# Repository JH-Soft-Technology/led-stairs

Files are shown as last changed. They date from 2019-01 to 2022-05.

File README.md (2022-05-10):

# Ledstairs

Microcontroller operating stairway lighting via motion sensors and light intensity sensor. Has two [PIR motion sensors](https://en.wikipedia.org/wiki/Passive_infrared_sensor) to detect human or animal movement.
The board also has a light sensitivity sensor that prevents from triggering when there is still enough light.

It has been designed to be modularly applied to stairs of different sizes. Individual boards can be joined together and thus the possibility of lighting up the stairs with the number 8/16/24/32 steps.

If for some reason there are fewer steps than 8 or 16 or 24 or 32. It is possible to light up such a number of steps. The required number of slabs is connected and only the number of required steps is involved. In addition, the slots will be empty.

## Schematic

Board has one 12V input terminal. It's different to old version, because the old one has input for 12V and 5V independently. New design has only 12V input and it is redist for inner circuit to 5V voltage.

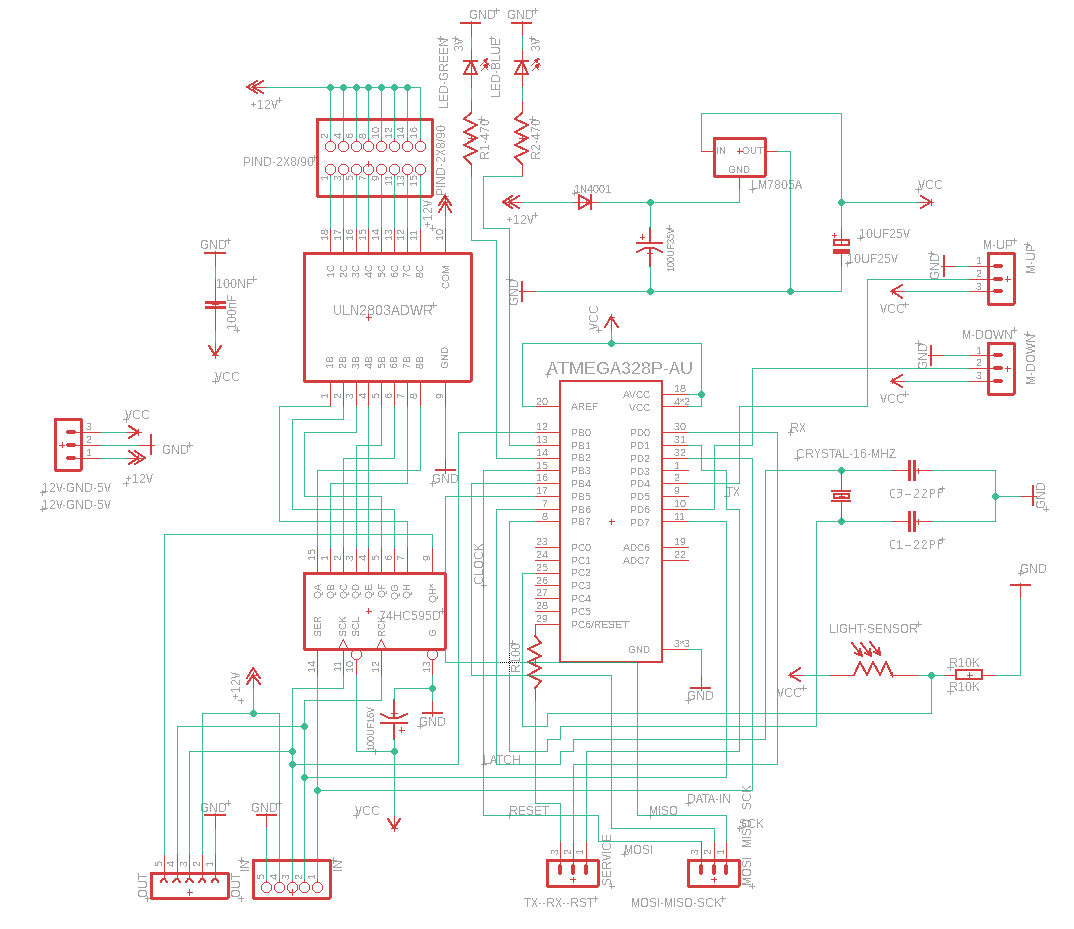
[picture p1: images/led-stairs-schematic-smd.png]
Schematic


## Design of the board

Board can be chained with up to 3 others. So maximal light management is 32 steps.

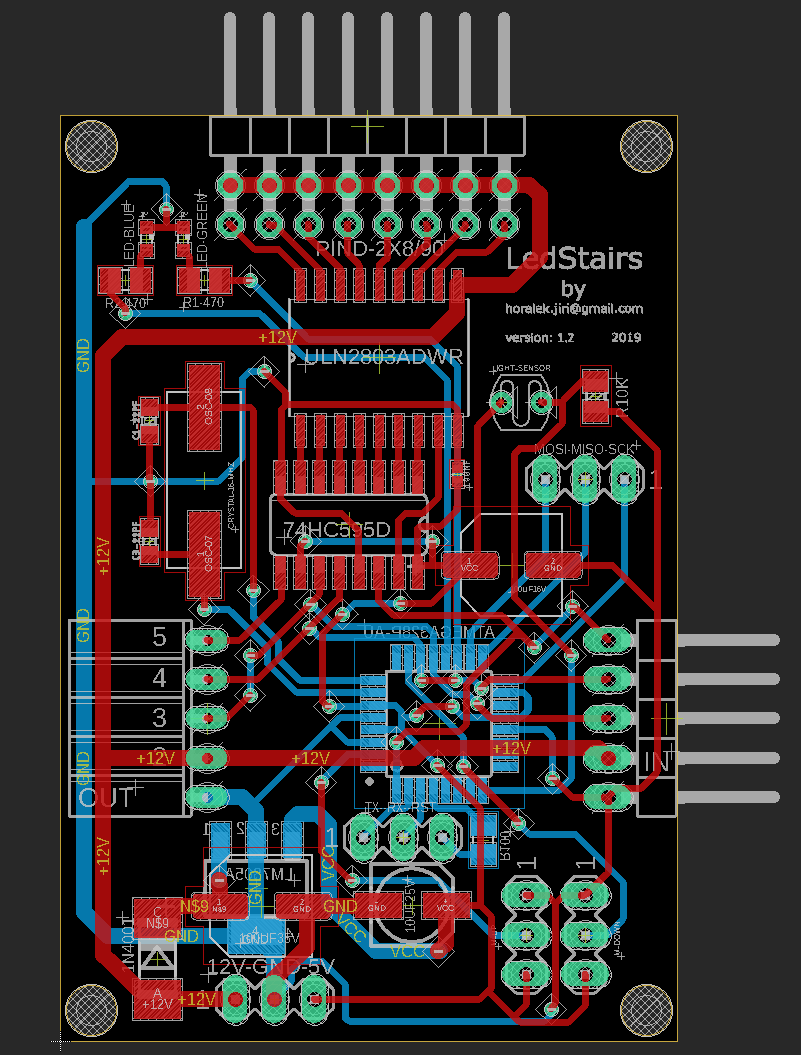
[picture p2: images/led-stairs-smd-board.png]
PCBdesign


## PCB board

It is double sided PCB board.

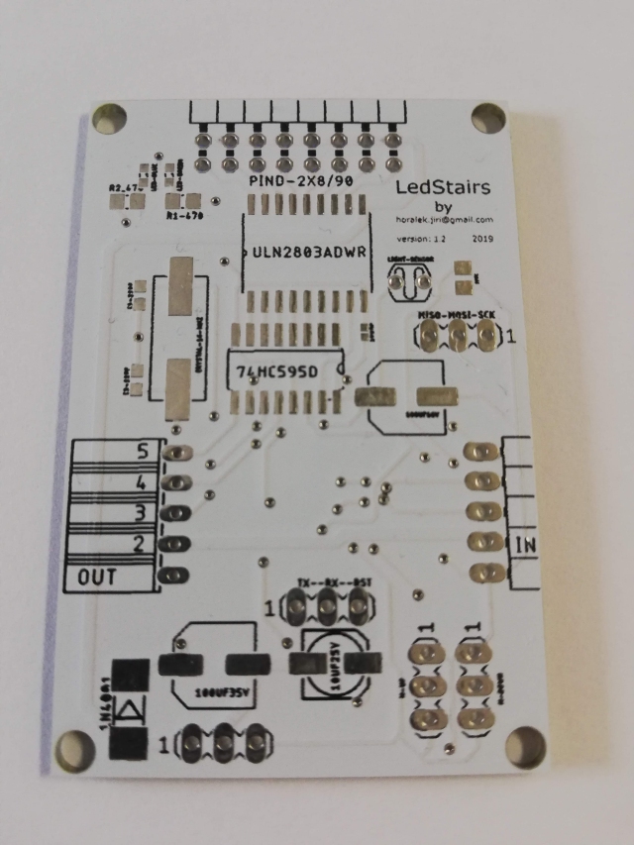
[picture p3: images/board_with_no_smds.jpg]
PCB


Master front side of the board with chips.

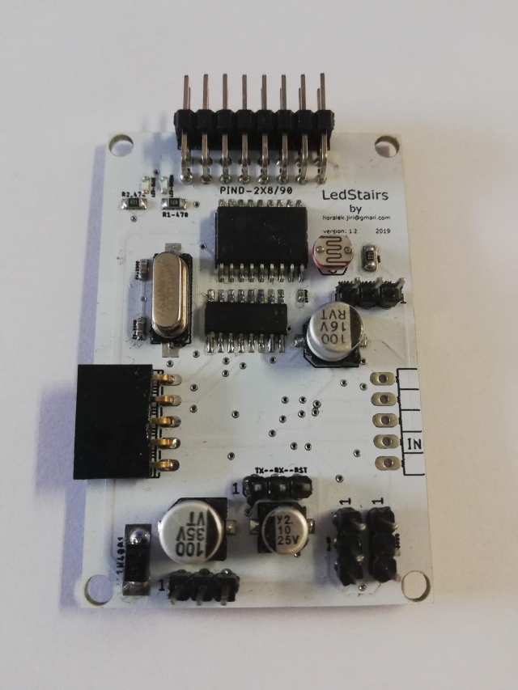
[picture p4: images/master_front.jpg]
PCBmasterFront


Master back side of the board with chips.

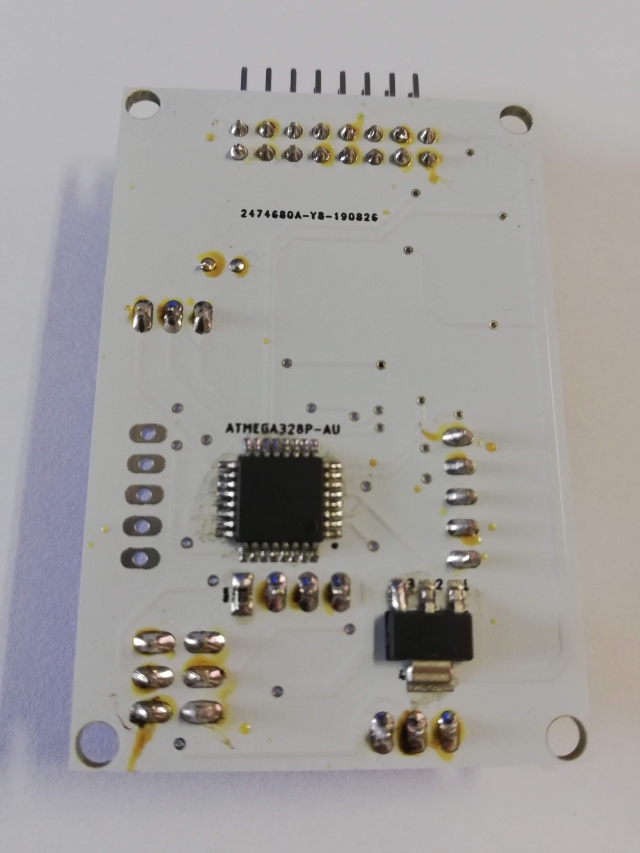
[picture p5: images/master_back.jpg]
PCBmasterBack


Master nad slave boards chained together.

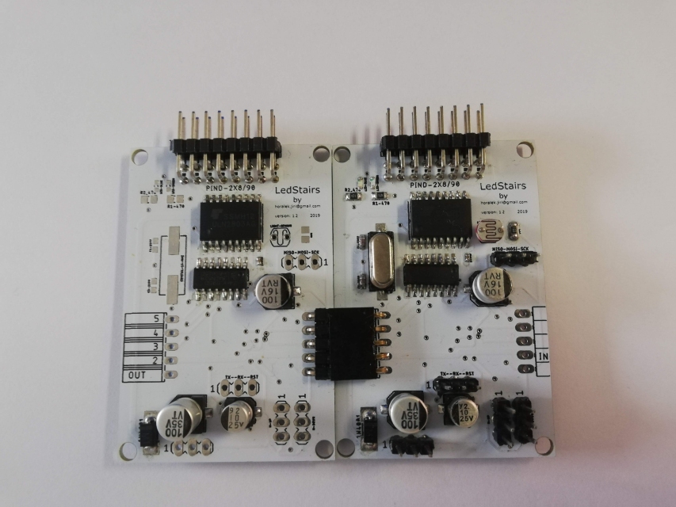
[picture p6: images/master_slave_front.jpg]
PCBmasterSlave


## How does it work

This board is turning on each step by step depends from which side is someone goes. Each step is turn on with little delay so it has nice effect. You can put a 12V LED strips to each step or
small light into the wall next to the each step. It depends on witch stairs you have.

In the feature, I'll put some video or moving picture in GIF format, how does it work.

## What you need to accomplish the project

- 12V power supply with current depends on number of the steps and length of LED strip. You need to calculate total current drain of all LED strips plus 25% extra for safe power supply operation.

Example:

```
You have 16 steps and each step has 70 cm long LED strip.
1m of led strip need 4,2 watts.

16 x 0,7 = 11,2m LED strip.

11,2 x 4,2 = 47,02 watts to all LED strips.

You need add 25% from 47,02 which is 58,75 watts.

So you need to by powers supply with 12V voltage and at least 60 watts. 60 watts for 12V power supply is 5 amps.
```

- 2 PIR sensor like [HC-SR501](https://www.amazon.com/HC-SR501/s?k=HC-SR501)
- A cable with two wires init. A cable cross section of at least 0,25 mm to each.
- Some 12V LED strips or lights at 12V.
- Some case for microcontroller and power supply.

## Visual

Up
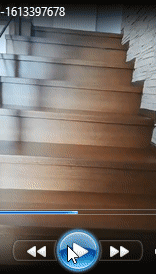
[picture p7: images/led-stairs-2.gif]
Down


## Authors

- **Jiří Horálek** - _Initial work_ - [jhoralek](https://github.com/jhoralek)

## License

This project is licensed under the MIT License - see the [LICENSE](LICENSE) file for details

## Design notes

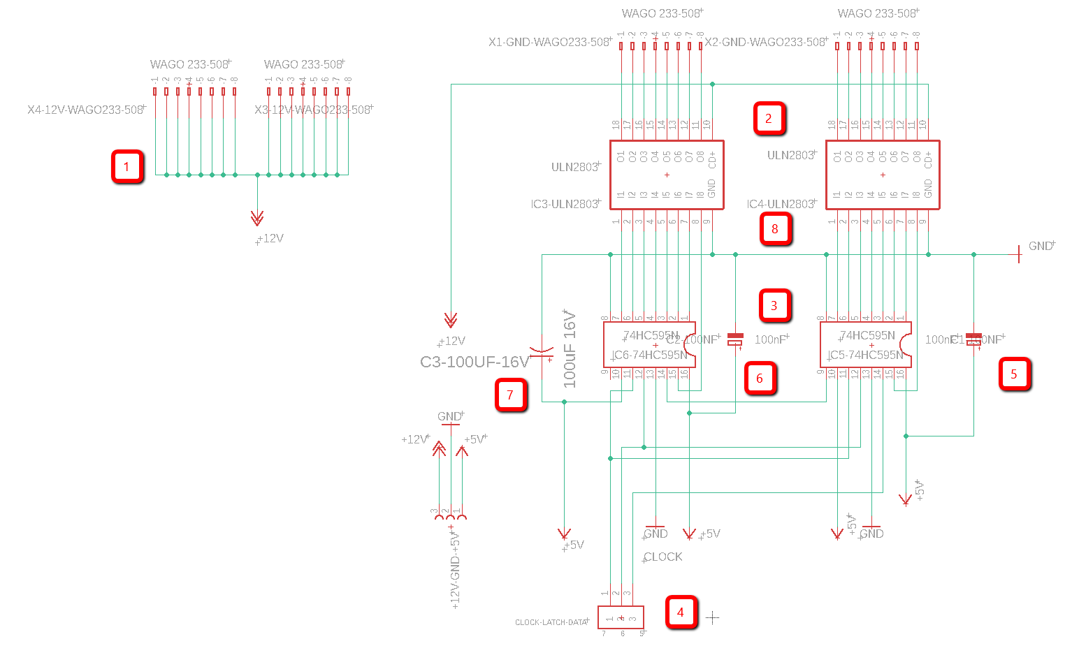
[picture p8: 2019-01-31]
images/schematic.png

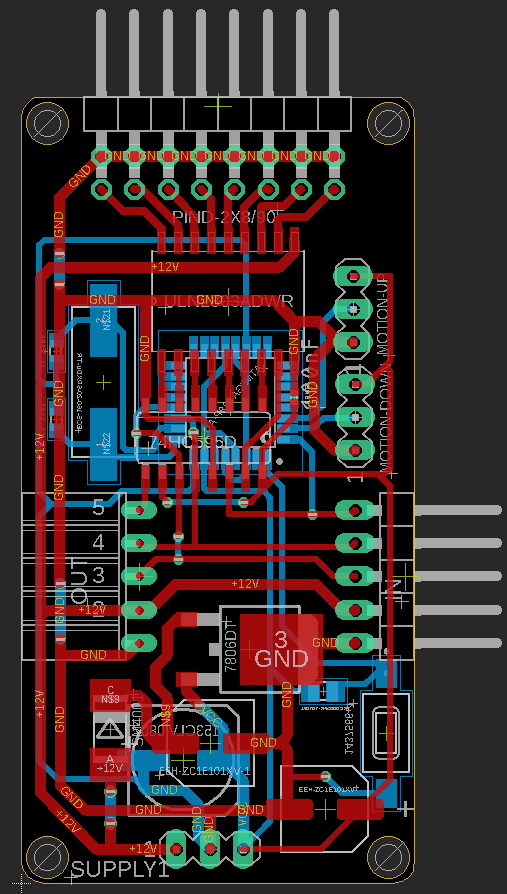
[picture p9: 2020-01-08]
images/board_upgrade.png

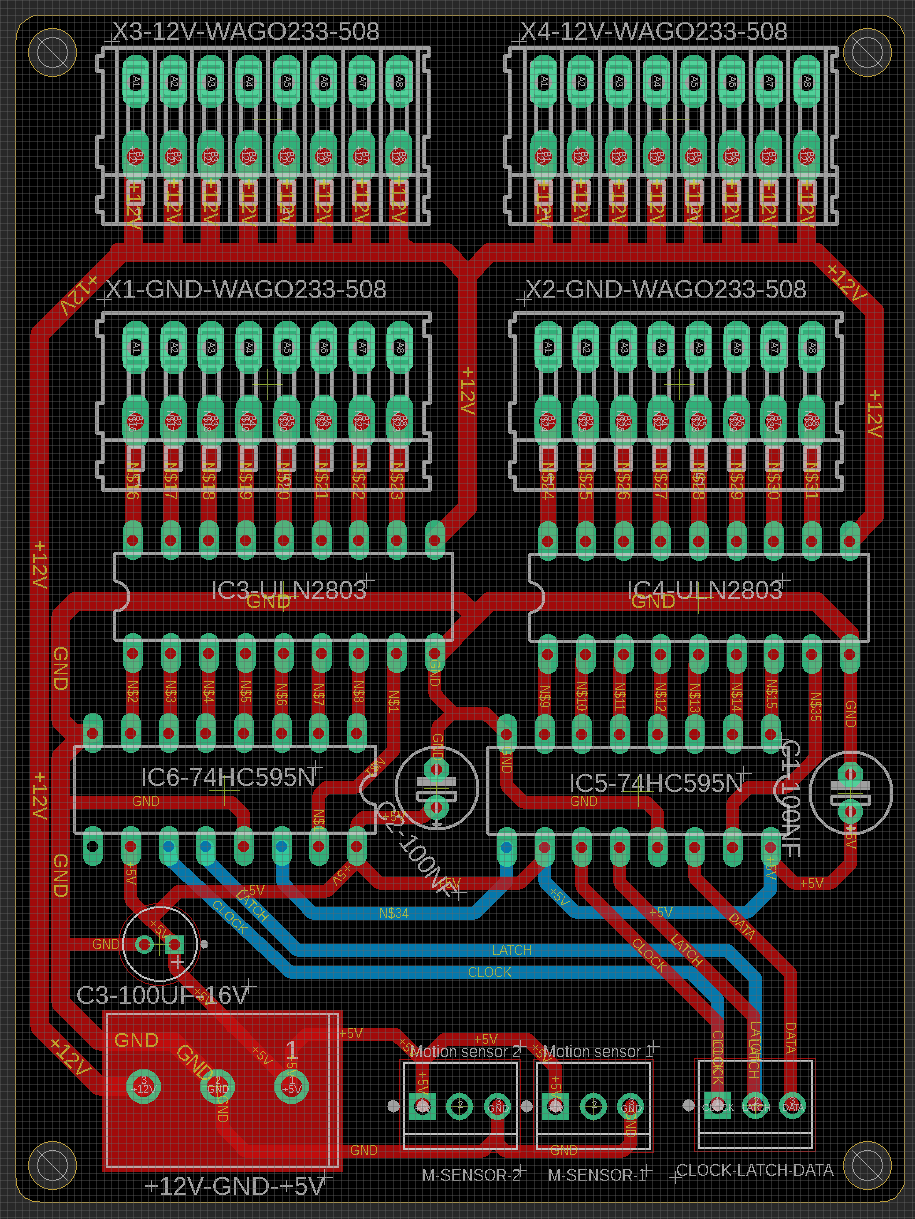
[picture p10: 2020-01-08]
images/board.png

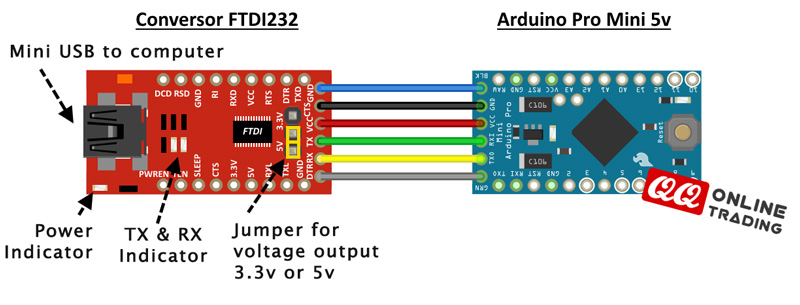
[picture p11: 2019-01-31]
images/arduino_wired_to_ftdi.jpg

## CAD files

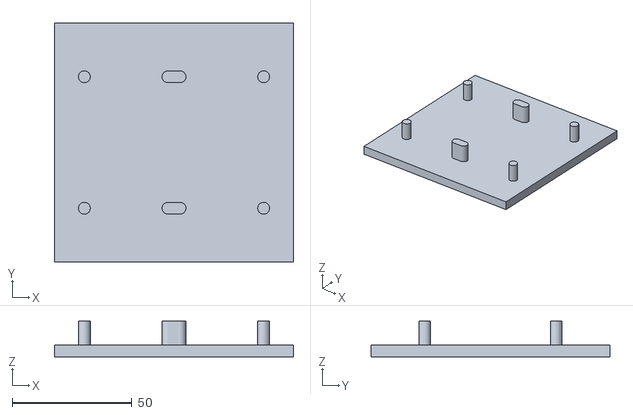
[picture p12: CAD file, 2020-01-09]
base_into_ko125e_wall_box.stl
100.0 x 100.0 x 15.0

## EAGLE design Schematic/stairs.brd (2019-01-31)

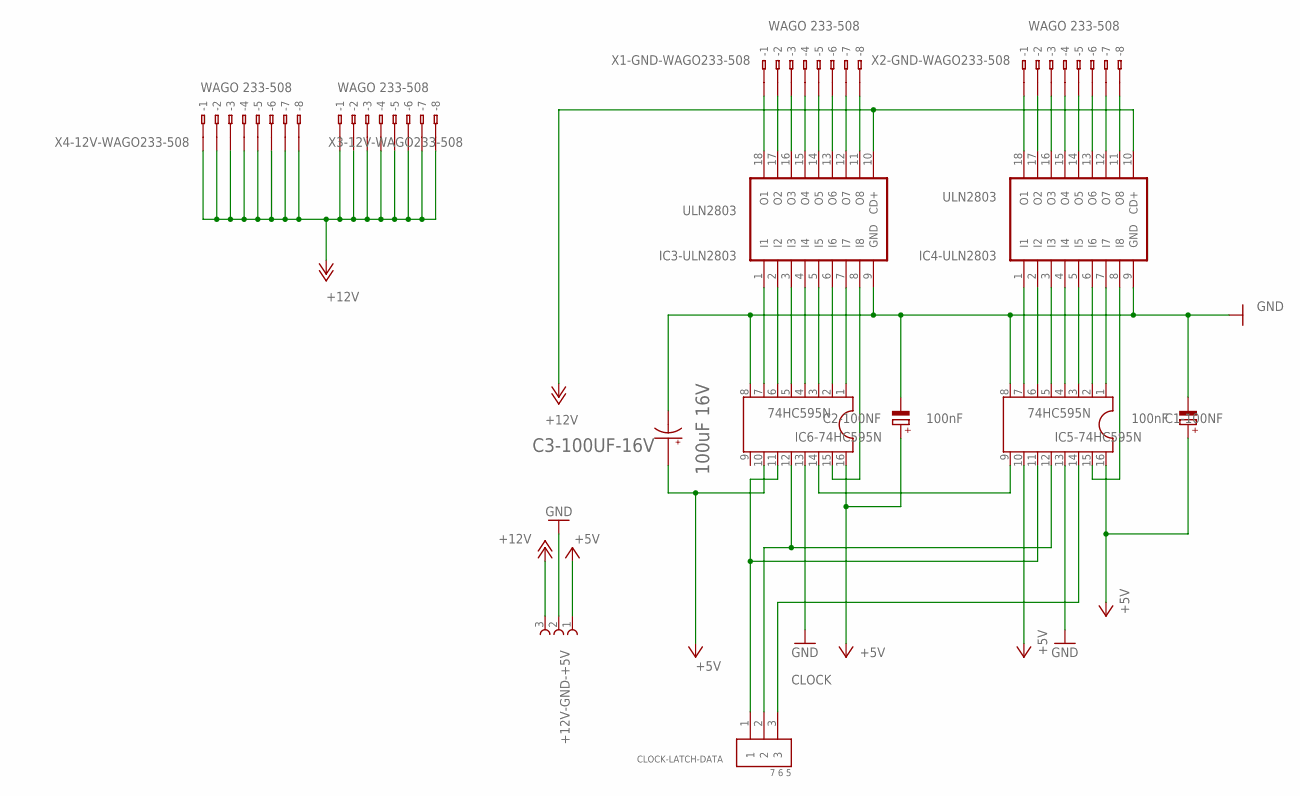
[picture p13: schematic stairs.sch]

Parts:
+12V-GND-+5V: +12V GND +5V; 691212710003
C1-100NF, C2-100NF: 100nF; E2,5-6E
C3-100UF-16V: 100uF 16V; CAPPRD200W50D500H1000
CLOCK-LATCH-DATA: 7 6 5; MOLEX_0022272031
IC3-ULN2803, IC4-ULN2803: ULN2803; DIL18
IC5-74HC595N, IC6-74HC595N: 74HC595N; DIL16
X1-GND-WAGO233-508, X2-GND-WAGO233-508, X3-12V-WAGO233-508, X4-12V-WAGO233-508: WAGO 233-508; 233-508

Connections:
+5V: +12V-GND-+5V.1, C1-100NF.+, C2-100NF.+, C3-100UF-16V.1, IC5-74HC595N.10, IC5-74HC595N.16, IC6-74HC595N.10, IC6-74HC595N.16
+12V: +12V-GND-+5V.3, IC3-ULN2803.10 (CD+), IC4-ULN2803.10 (CD+), X3-12V-WAGO233-508.B1 (B-1), X3-12V-WAGO233-508.B2 (B-2), X3-12V-WAGO233-508.B3 (B-3), X3-12V-WAGO233-508.B4 (B-4), X3-12V-WAGO233-508.B5 (B-5), X3-12V-WAGO233-508.B6 (B-6), X3-12V-WAGO233-508.B7 (B-7), X3-12V-WAGO233-508.B8 (B-8), X4-12V-WAGO233-508.B1 (B-1), X4-12V-WAGO233-508.B2 (B-2), X4-12V-WAGO233-508.B3 (B-3), X4-12V-WAGO233-508.B4 (B-4), X4-12V-WAGO233-508.B5 (B-5), X4-12V-WAGO233-508.B6 (B-6), X4-12V-WAGO233-508.B7 (B-7), X4-12V-WAGO233-508.B8 (B-8)
CLOCK: CLOCK-LATCH-DATA.3, IC5-74HC595N.14
GND: +12V-GND-+5V.2, C1-100NF.-, C2-100NF.-, C3-100UF-16V.2 (N), IC3-ULN2803.9 (GND), IC4-ULN2803.9 (GND), IC5-74HC595N.8, IC5-74HC595N.13, IC6-74HC595N.8, IC6-74HC595N.13
unnamed: IC3-ULN2803.8 (I8), IC6-74HC595N.15
unnamed: IC3-ULN2803.1 (I1), IC6-74HC595N.7
unnamed: IC3-ULN2803.2 (I2), IC6-74HC595N.6
unnamed: IC3-ULN2803.3 (I3), IC6-74HC595N.5
unnamed: IC3-ULN2803.4 (I4), IC6-74HC595N.4
unnamed: IC3-ULN2803.5 (I5), IC6-74HC595N.3
unnamed: IC3-ULN2803.6 (I6), IC6-74HC595N.2
unnamed: IC3-ULN2803.7 (I7), IC6-74HC595N.1
unnamed: IC4-ULN2803.1 (I1), IC5-74HC595N.7
unnamed: IC4-ULN2803.2 (I2), IC5-74HC595N.6
unnamed: IC4-ULN2803.3 (I3), IC5-74HC595N.5
unnamed: IC4-ULN2803.4 (I4), IC5-74HC595N.4
unnamed: IC4-ULN2803.5 (I5), IC5-74HC595N.3
unnamed: IC4-ULN2803.6 (I6), IC5-74HC595N.2
unnamed: IC4-ULN2803.7 (I7), IC5-74HC595N.1
unnamed: IC3-ULN2803.18 (O1), X1-GND-WAGO233-508.B1 (B-1)
unnamed: IC3-ULN2803.17 (O2), X1-GND-WAGO233-508.B2 (B-2)
unnamed: IC3-ULN2803.16 (O3), X1-GND-WAGO233-508.B3 (B-3)
unnamed: IC3-ULN2803.15 (O4), X1-GND-WAGO233-508.B4 (B-4)
unnamed: IC3-ULN2803.14 (O5), X1-GND-WAGO233-508.B5 (B-5)
unnamed: IC3-ULN2803.13 (O6), X1-GND-WAGO233-508.B6 (B-6)
unnamed: IC3-ULN2803.12 (O7), X1-GND-WAGO233-508.B7 (B-7)
unnamed: IC3-ULN2803.11 (O8), X1-GND-WAGO233-508.B8 (B-8)
unnamed: IC4-ULN2803.18 (O1), X2-GND-WAGO233-508.B1 (B-1)
unnamed: IC4-ULN2803.17 (O2), X2-GND-WAGO233-508.B2 (B-2)
unnamed: IC4-ULN2803.16 (O3), X2-GND-WAGO233-508.B3 (B-3)
unnamed: IC4-ULN2803.15 (O4), X2-GND-WAGO233-508.B4 (B-4)
unnamed: IC4-ULN2803.14 (O5), X2-GND-WAGO233-508.B5 (B-5)
unnamed: IC4-ULN2803.13 (O6), X2-GND-WAGO233-508.B6 (B-6)
unnamed: IC4-ULN2803.12 (O7), X2-GND-WAGO233-508.B7 (B-7)
unnamed: IC4-ULN2803.11 (O8), X2-GND-WAGO233-508.B8 (B-8)
unnamed: CLOCK-LATCH-DATA.1, IC5-74HC595N.11, IC6-74HC595N.11
unnamed: CLOCK-LATCH-DATA.2, IC5-74HC595N.12, IC6-74HC595N.12
unnamed: IC5-74HC595N.9, IC6-74HC595N.14
unnamed: IC4-ULN2803.8 (I8), IC5-74HC595N.15

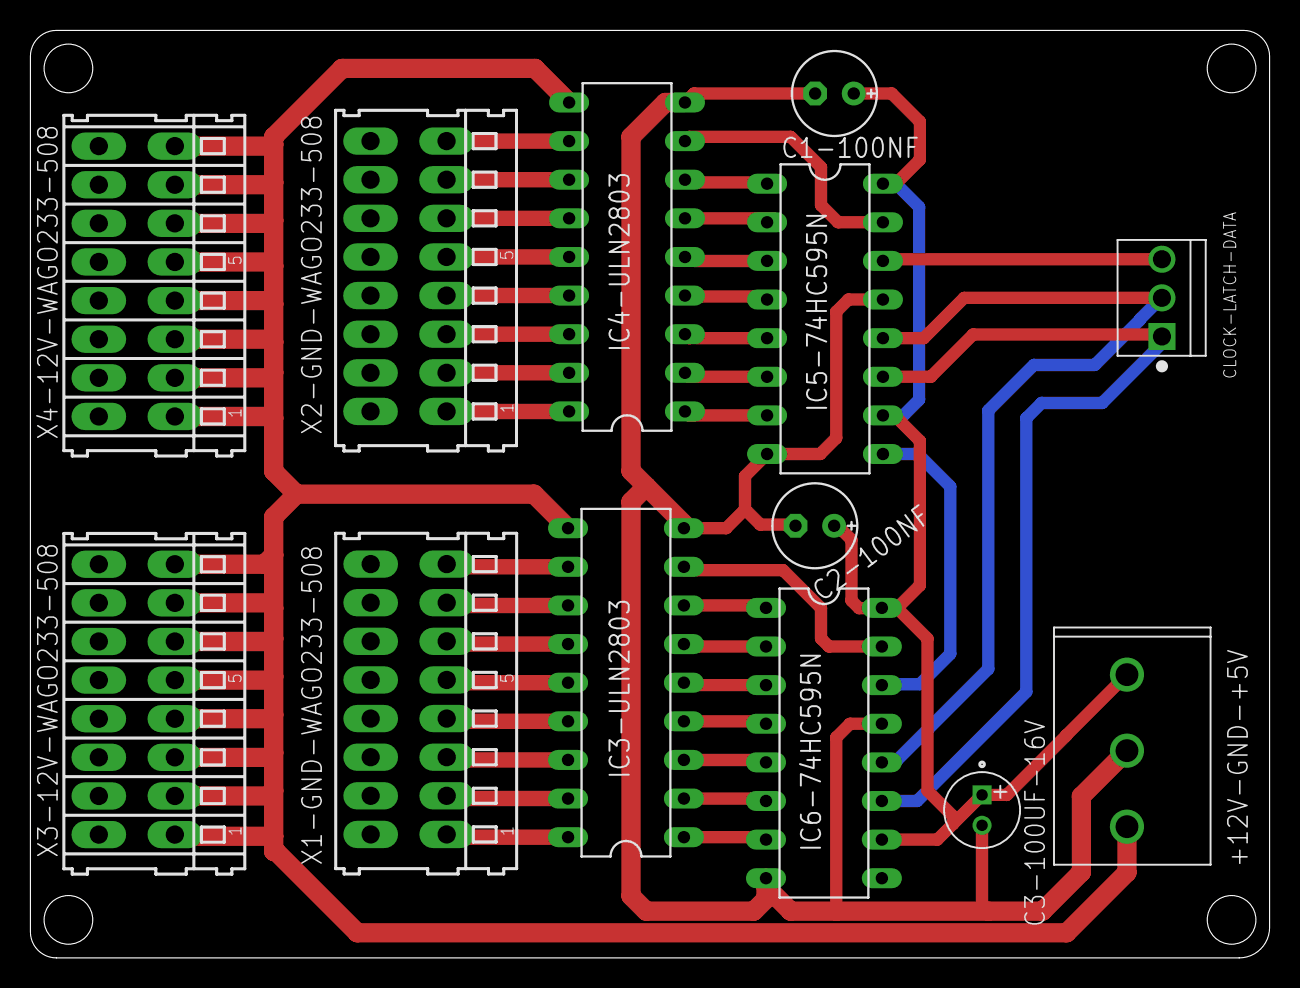
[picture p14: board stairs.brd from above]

Board: 2 copper layers, 81.5 x 61.0 mm, 13 parts (0 on the bottom side), 39 nets.

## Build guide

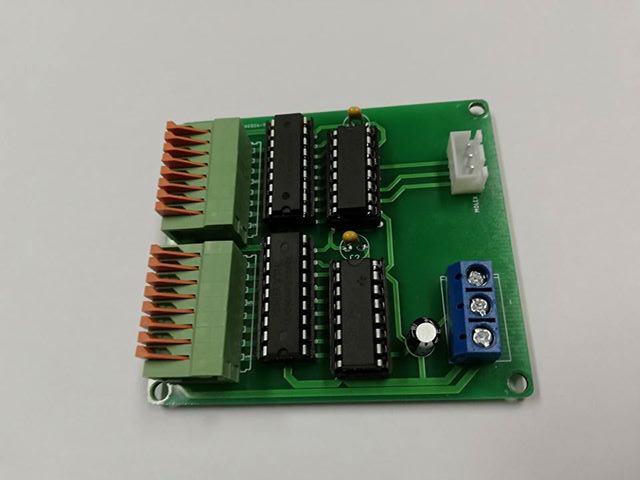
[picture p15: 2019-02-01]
images/solderedboard.jpg

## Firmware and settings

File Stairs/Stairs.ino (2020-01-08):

/* Number of used registers */
int numOfRegisters = 2;
/* Number of staris */
int numberOfStairs = 16;

int blueLed = 10;
int greenLed = 9;

int dataPin = 2; /* Atmega 328P pin 32 */
int latchPin = 7; /* Atmega 328P pin 11 */
int clockPin = 8; /* Atmega 328P pin 12 */

/* Light sensor */
unsigned int lightSensorPin = A2; /* Atmega328P pin 25 */

/* motion sensors upstairs and downstairs */
int sensorDownstairs = 6; /* Atmega 328P pin 10 */
int sensorUpstairs = 4; /* Atmega 328P pin 2 */

/* speeds */
int speedUp = 250;
int speedDown = 200;

/* lights turn on for some time in miliseconds */
int lightsOnDelay = 10000;

byte *registerState;

// when move is captured then do the action
bool hasMoved = false;
bool wasDownToUp = false;
bool wasUpToDown = false;

void setup()
{
  Serial.begin(9600);
  // setup registers
  registerState = new byte[numOfRegisters];
  for (size_t i = 0; i < numOfRegisters; i++)
  {
    registerState[i] = 0;
  }

  // setup pins
  pinMode(sensorDownstairs, INPUT);
  pinMode(sensorUpstairs, INPUT);
  pinMode(latchPin, OUTPUT);
  pinMode(clockPin, OUTPUT);
  pinMode(dataPin, OUTPUT);  
  pinMode(blueLed, OUTPUT);
  pinMode(greenLed, OUTPUT);

  digitalWrite(greenLed, HIGH);  
}

/**
 * Reed motion sensors upstairs and downstairs
 * When move is detected wherever upstairs or downstairs
 * turn the lighs on
 *
 * When lights are turning on from downstairs to upstaris then
 * turning them off is from the same direction and vice versa.
 */
void loop()
{
  // read the sensors
  int motionUp = digitalRead(sensorUpstairs); // move from downstairs to upstairs
  int motionDown = digitalRead(sensorDownstairs); // move from upstairs to downstairs
  int lightSensor = analogRead(lightSensorPin); // get the light sensitivity

  Serial.print("Light level: ");
  Serial.println(lightSensor);
  Serial.print("MotionUP: ");
  Serial.println(motionUp);
  Serial.print("MotionDown: ");
  Serial.println(motionDown);

  // when motion it does not metter where
  // marke as hasMoved
  if ((motionUp || motionDown) /*&& lightSensor > 200*/)
  {    
    Serial.print("Moving changing from ");
    Serial.print(hasMoved);
    hasMoved = true;
    Serial.print(" to ");
    Serial.println(hasMoved);
  }

  if (hasMoved)
  {
    digitalWrite(blueLed, HIGH);
    if (motionUp)
    {      
      Serial.println("Turning on from downsatirs");
      turnOnFromDownstairs(speedUp);
      wasDownToUp = true;
    }
    if (motionDown)
    {
      Serial.println("Turning on from upstairs");
      turnOnFromUpstairs(speedUp);
      wasUpToDown = true;
    }

    Serial.print("Moving changing from ");
    Serial.print(hasMoved);
    hasMoved = false;
    Serial.print(" to ");
    Serial.println(hasMoved);
    
    delay(lightsOnDelay);
  }
  else
  {
    if (wasDownToUp)
    {
      Serial.println("Turning off from downstairs");
      turnOffFromDownstairs(speedDown);
      wasDownToUp = false;
      digitalWrite(blueLed, LOW);
    }
    if (wasUpToDown)
    {
      Serial.println("Turning off from upstairs");
      turnOffFromUpstairs(speedDown);
      wasUpToDown = false;
      digitalWrite(blueLed, LOW);
    }
  }
}

/**
 * Turn the lights off from upstairs
 * @param effectSpeed - speed of lights bringing off
 */
void turnOffFromUpstairs(int effectSpeed)
{
  changeState(effectSpeed, LOW, false);
}

/**
 * Turn the lights on from upstairs
 * @param effectSpeed - speed of lights bringing on
 */
void turnOnFromUpstairs(int effectSpeed)
{
  changeState(effectSpeed, HIGH, false);
}

/**
 * Turn the lights off from downdstairs
 * @param effectSpeed - speed of lights bringing off
 */
void turnOffFromDownstairs(int effectSpeed)
{
  changeState(effectSpeed, LOW, true);
}

/**
 * Turn the lights on from downdstairs
 * @param effectSpeed - speed of lights bringing on
 */
void turnOnFromDownstairs(int effectSpeed)
{
  changeState(effectSpeed, HIGH, true);
}

/**
 * Method changing state of lights
 * @param effectSpeed - int speed in miliseconds
 * @param state  - HIGH / LOW
 * @param directionUp - when True then lights direction is from Down to Up
 * when False then direction from Up to Down
 */
void changeState(int effectSpeed, bool state, bool directionUp)
{
  if (directionUp)
  {
    for (int i = 0; i < numberOfStairs; i++)
    {
      regWrite(i, state);
      delay(effectSpeed);
    }
  }
  else
  {
    for (int i = numberOfStairs; i >= 0; i--)
    {
      regWrite(i, state);
      delay(effectSpeed);
    }
  }
}

/**
 * Method write to the shift register
 * @param pin - pin position where to write state
 * @param state - state to write HIGH / LOW
 */
void regWrite(int pin, bool state)
{
  int reg = pin / 8;
  int actualPin = pin - (8 * reg);

  digitalWrite(latchPin, LOW);

  for (int i = numOfRegisters; i >= 0; i--)
  {
    byte *states = &registerState[i];

    if (i == reg)
    {
      bitWrite(*states, actualPin, state);
    }
    shiftOut(dataPin, clockPin, MSBFIRST, *states);
  }
  digitalWrite(latchPin, HIGH);
}

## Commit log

2019-01-31 Eagle - schematic and pcb design
    [stairs.brd, stairs.sch]
2020-01-09 base for board into the wall box
    [base_into_ko125e_wall_box.stl]
